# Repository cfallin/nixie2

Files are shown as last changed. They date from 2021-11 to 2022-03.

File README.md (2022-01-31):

# GPS-synchronized Nixie tube clock

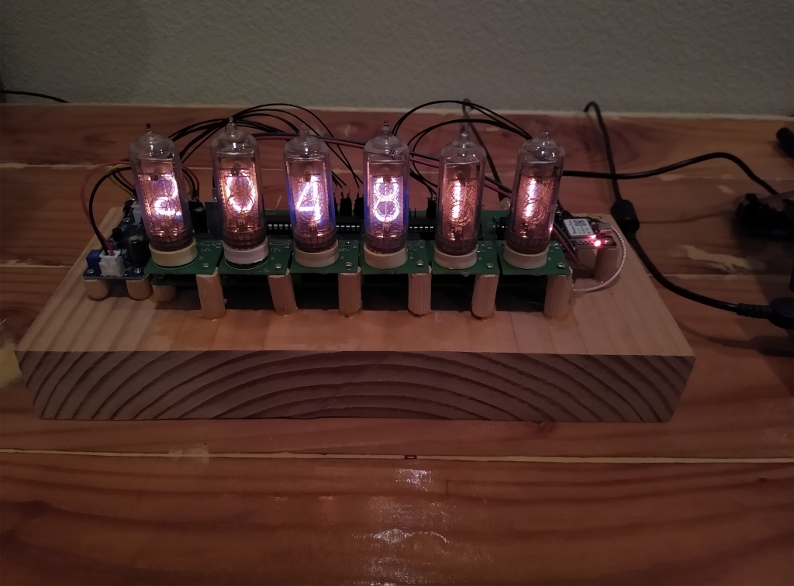
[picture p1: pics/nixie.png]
view of Nixie clock with HH:MM:SS glowing orange digits


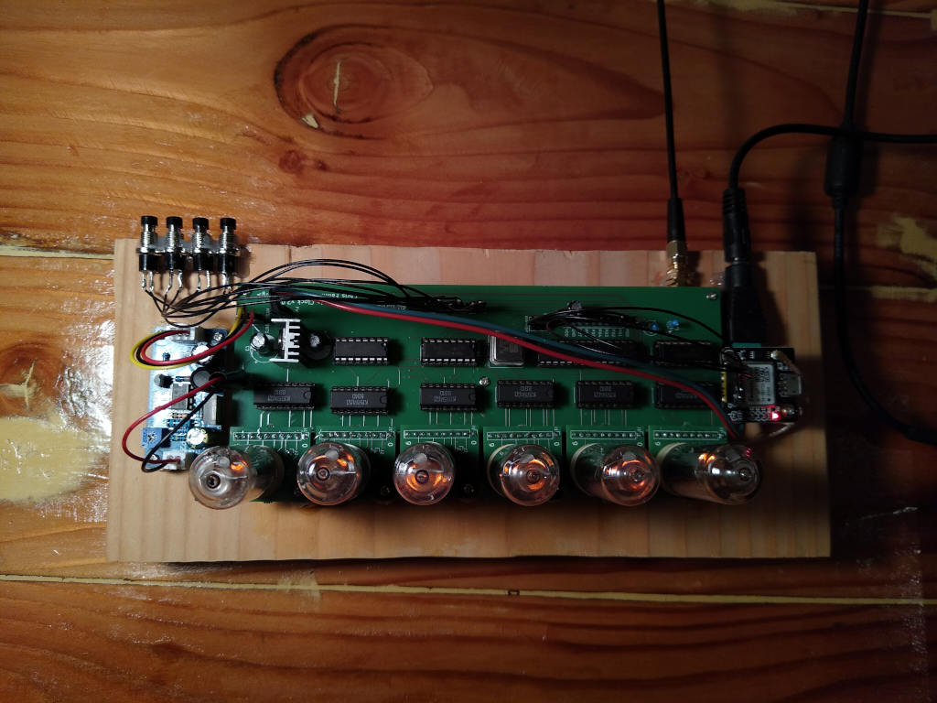
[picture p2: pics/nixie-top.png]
view of Nixie clock from the top, showing circuit boards


This is a custom-designed (custom circuit design / PCB boards and custom
microcontroller firmware) digital clock. It receives the time from a GPS
receiver board, adjusts for an user-selectable timezone, and displays the time
on "Nixie tubes". A [nixie tube](https://en.wikipedia.org/wiki/Nixie_tube) is a
cold-cathode vacuum tube display technology: it uses high voltage (about 160
volts in this design) applied to an electrode in the shape of a digit in order
to display a number in brilliant glowing orange. It really is quite
mesmerizing!

This repo contains custom circuit board layouts for the main clock board and a
separate adapter sub-board for each Nixie tube. The sub-boards are designed for
IN-14 tubes (which can currently be found on eBay or Etsy for ~$20 each), but
could be adapted for IN-12, IN-18, or some other size.

The main board contains an AVR ATmega8 microcontroller, a 20MHz crystal,
several 74HC595 shift registers to expand the AVR's IO, and six KI155ID1
open-collector high voltage driver chips.

The board interfaces with a separate high-voltage DC-DC power supply, because
designing such a supply to be efficient is quite hard and I do not possess the
analog black magic skills! I bought [this
one](https://www.amazon.com/gp/product/B09D94N3MX) for $11. You can substitute
any suitable source of ~160V DC rated for about 4mA per tube (24mA total, or
just under 4 watts).

GPS is also black magic, so I bought a pre-designed GPS receiver module
[here](https://www.amazon.com/gp/product/B07P8YMVNT) for $12, and an external
active antenna [here](https://www.amazon.com/gp/product/B083D59N55) for $11.
The module provides a 1Hz "pulse-per-second" precision output and a 9600bps
serial line providing time, position, and satellite lock information using the
[NMEA](https://en.wikipedia.org/wiki/NMEA_0183) protocol. You can substitute
any GPS receiver that provides a PPS output and NMEA signal.

The ATmega8 runs firmware that decodes the NMEA to get an initial time
(synchronizing whenever a valid NMEA packet with a timestamp is received). It
measures the internal crystal oscillator against the PPS and then ticks based
on the main CPU clock, calibrated with this ticks-per-PPS value. This allows
the clock to receive the time when GPS signal is available, learn how fast or
slow its own internal oscillator is running, and then continue to keep time
when the GPS signal is lost. Whenever it comes back, time will resynchronize
automatically.

There is a simple user interface consisting of four buttons. The leftmost (SW4
on the main board) switches between time mode and set-timezone mode. In the
latter, SW2 decrements TZ offset hour and SW1 increments TZ offset hour.
(Half-hour or 15 minute timezone offsets are not yet supported; I know these
timezones exist, sorry! Happy to take PRs if anyone in such a timezone builds
this clock!)

Total cost for the clock, not including the one-time tool purchases I made
(e.g. an AVR programmer) or the scrap wood, glue, etc. for the very janky base,
and definitely not including my time, was about $230:

- $42 for the PCBs (mainboard and 6x nixie tube adapters) at Aisler.net
- $90 for the six IN-14s, on Etsy
- $22 for the KI155ID1 driver chips
- $12 for the GPS receiver
- $11 for the GPS antenna
- $11 for the 160V DC supply
- about $40 for the ATmega8, 20MHz crystal, 74HC595s, a few resistors and
  capacitors, pin headers, wire, etc.

I started thinking about building a Nixie clock in 2014, but started working on
this design regularly in Nov 2021. It first displayed a GPS-synchronized time
on Jan 6, 2022. I'd like to improve the UI a bit (allow a non-GPS
locally-set-time mode as well), and definitely improve the casing, but it suits
me well enough for now! I finally know what time it is!

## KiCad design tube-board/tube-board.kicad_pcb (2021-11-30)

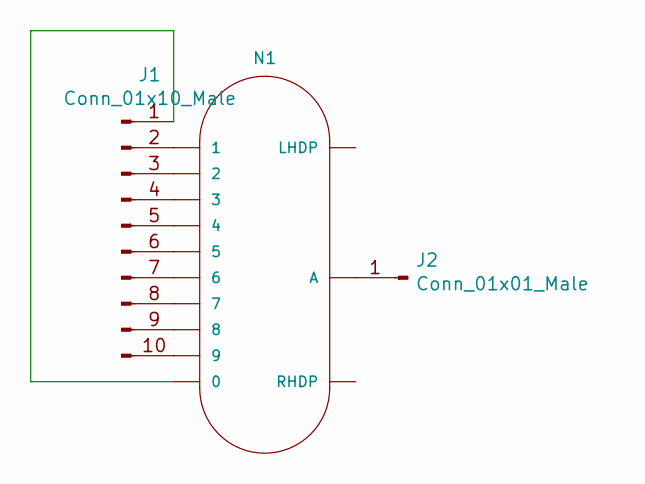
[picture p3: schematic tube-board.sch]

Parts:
J1: Conn_01x10_Male; PinHeader_1x10_P2.54mm_Vertical
J2: Conn_01x01_Male; PinHeader_1x01_P2.54mm_Vertical
N1: IN-14

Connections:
unnamed: J1.1, N1.0
unnamed: J1.2, N1.1
unnamed: J1.3, N1.2
unnamed: J1.4, N1.3
unnamed: J1.5, N1.4
unnamed: J1.6, N1.5
unnamed: J1.7, N1.6
unnamed: J1.8, N1.7
unnamed: J1.9, N1.8
unnamed: J1.10, N1.9
unnamed: J2.1, N1.A

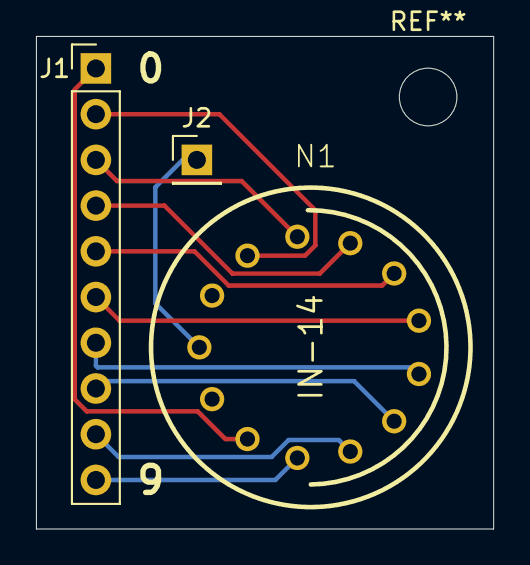
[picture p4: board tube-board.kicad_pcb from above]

Board: 2 copper layers, 25.4 x 27.4 mm, 3 parts (0 on the bottom side), 11 nets.

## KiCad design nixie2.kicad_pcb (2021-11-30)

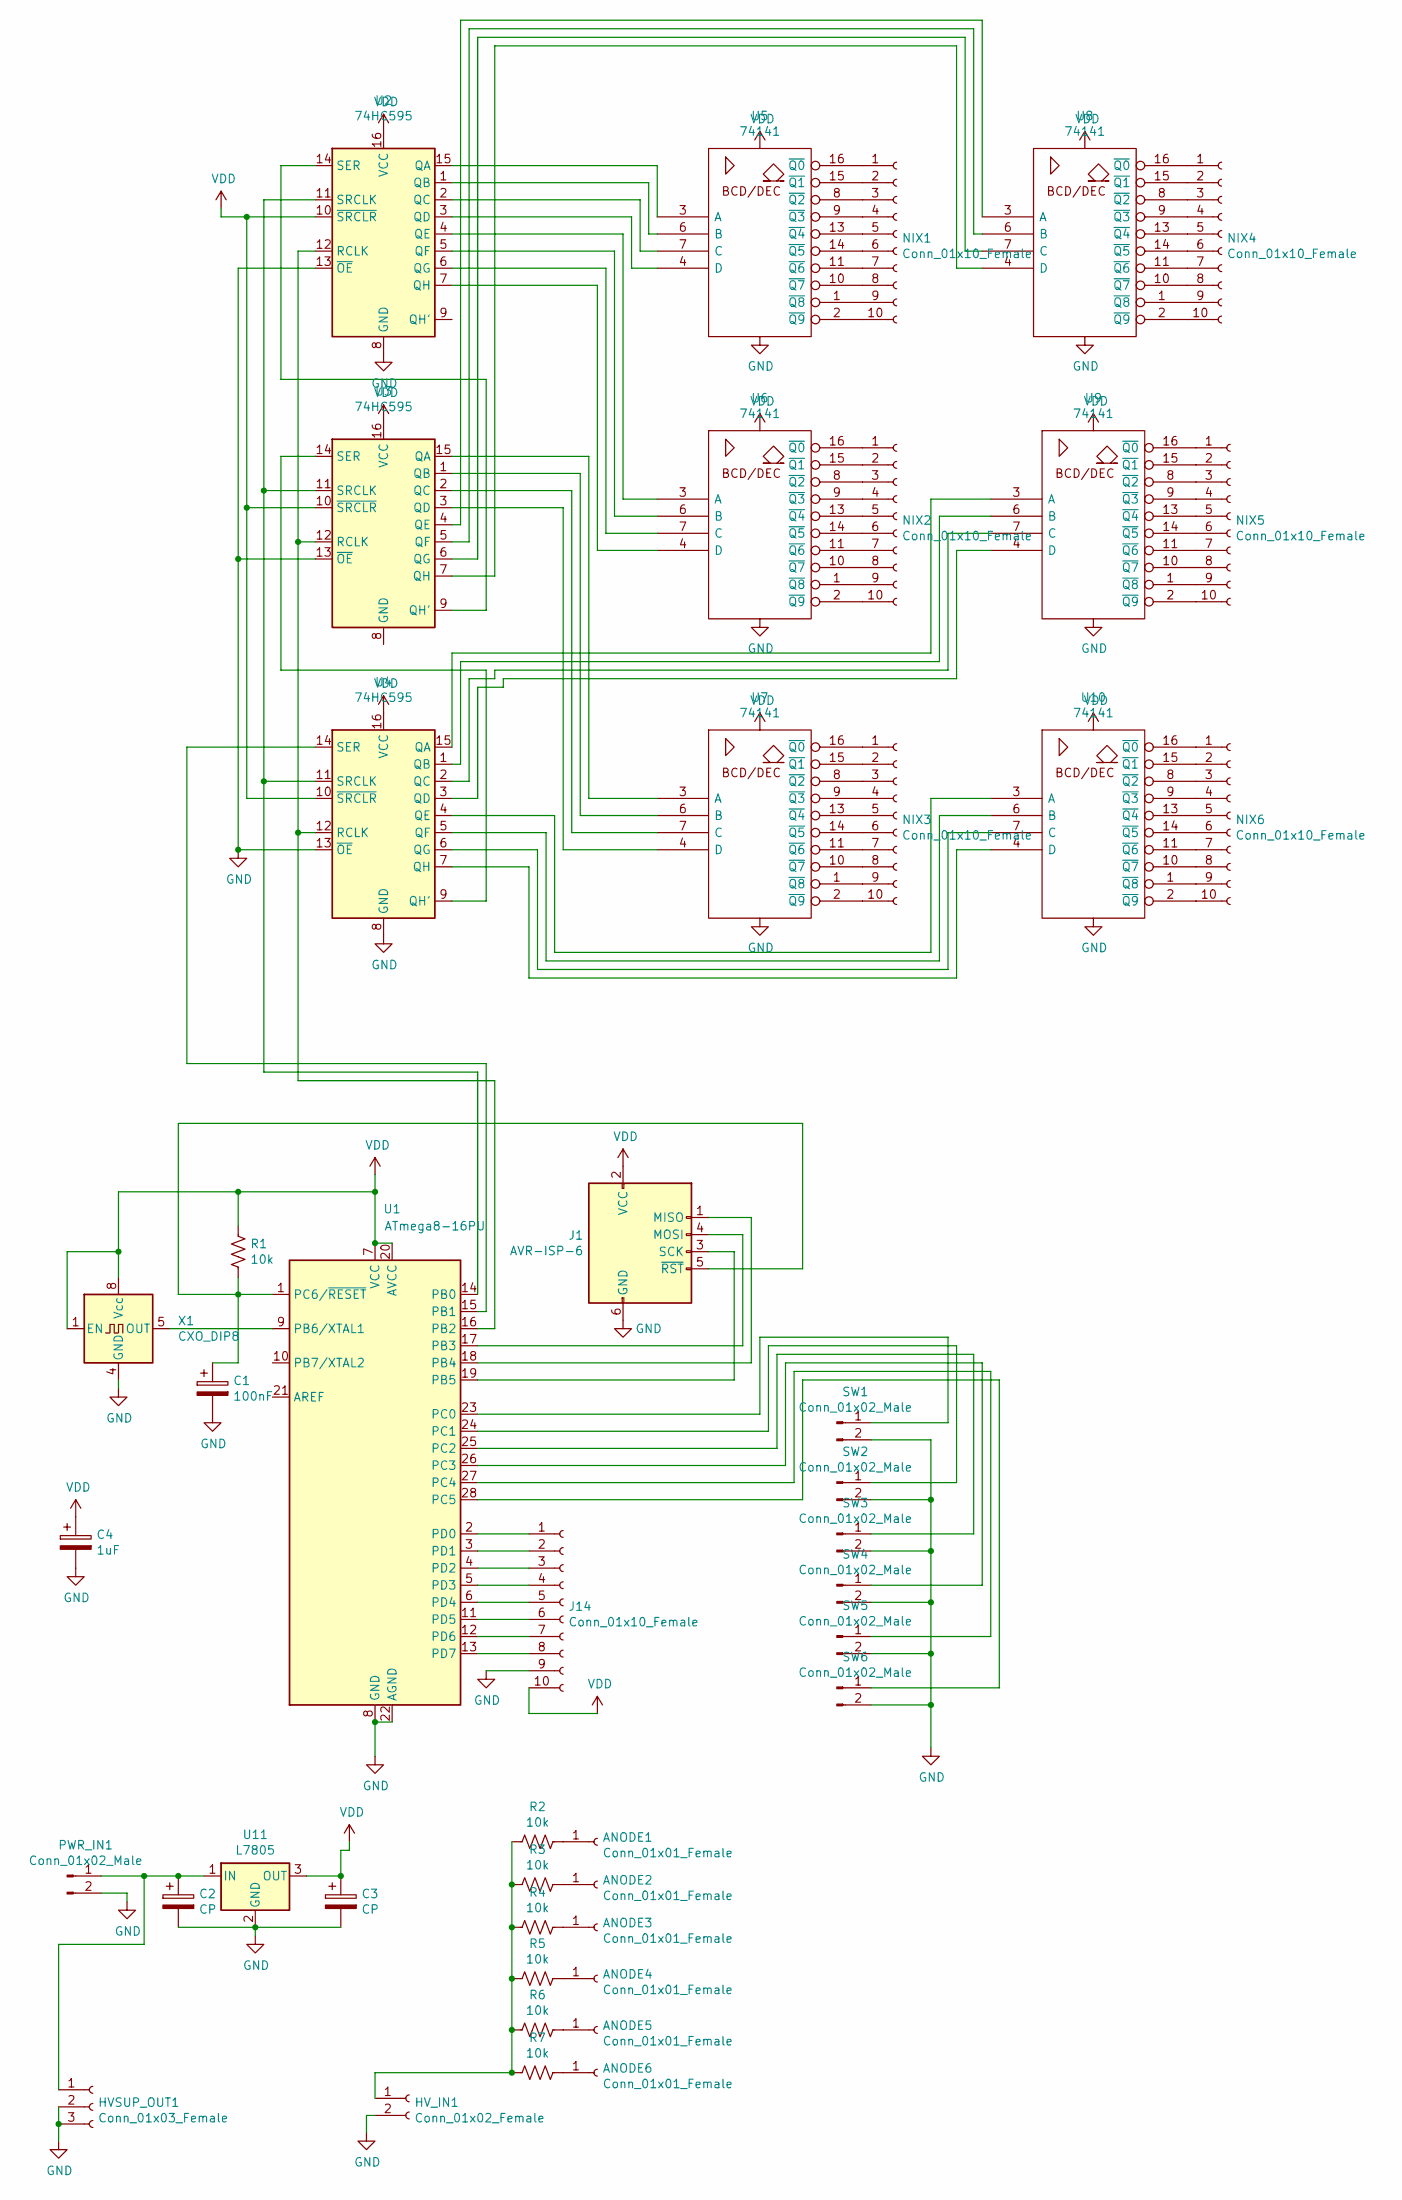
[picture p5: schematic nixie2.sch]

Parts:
ANODE1, ANODE2, ANODE3, ANODE4, ANODE5, ANODE6: Conn_01x01_Female; PinHeader_1x01_P2.54mm_Vertical
C1: 100nF; CP_Radial_Tantal_D5.5mm_P2.50mm
C2, C3: CP; CP_Radial_D10.0mm_P2.50mm
C4: 1uF; CP_Radial_D4.0mm_P1.50mm
HVSUP_OUT1: Conn_01x03_Female; PinHeader_1x03_P2.54mm_Vertical
HV_IN1: Conn_01x02_Female; PinHeader_1x02_P2.54mm_Vertical
J1: AVR-ISP-6; PinHeader_2x03_P2.54mm_Vertical
J14: Conn_01x10_Female; PinHeader_1x10_P2.54mm_Vertical
NIX1, NIX2, NIX3, NIX4, NIX5, NIX6: Conn_01x10_Female; PinHeader_1x10_P2.54mm_Vertical
PWR_IN1: Conn_01x02_Male; PinHeader_1x02_P2.54mm_Vertical
R1: 10k; R_Axial_DIN0207_L6.3mm_D2.5mm_P2.54mm_Vertical
R2, R3, R4, R5, R6, R7: 10k; R_Axial_DIN0207_L6.3mm_D2.5mm_P7.62mm_Horizontal
SW1, SW2, SW3, SW4, SW5, SW6: Conn_01x02_Male; PinHeader_1x02_P2.54mm_Vertical
U1: ATmega8-16PU; DIP-28_W7.62mm
U2, U3, U4: 74HC595; DIP-16_W7.62mm
U5, U6, U7, U8, U9, U10: 74141; DIP-16_W7.62mm
U11: L7805; TO-220-3_Vertical
X1: CXO_DIP8; Oscillator_DIP-8

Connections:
GND: C1.2, C2.2, C3.2, C4.2, HVSUP_OUT1.2, HVSUP_OUT1.3, HV_IN1.2, J1.6 (GND), J14.9, PWR_IN1.2, SW1.2, SW2.2, SW3.2, SW4.2, SW5.2, SW6.2, U1.8 (GND), U1.22 (AGND), U2.8 (GND), U2.13 (~OE), U3.13 (~OE), U4.8 (GND), U4.13 (~OE), U5.12 (GND), U6.12 (GND), U7.12 (GND), U8.12 (GND), U9.12 (GND), U10.12 (GND), U11.2 (GND), X1.4 (GND)
unnamed: ANODE1.1, R2.1
unnamed: ANODE2.1, R3.1
unnamed: ANODE3.1, R4.1
unnamed: ANODE4.1, R5.1
unnamed: ANODE5.1, R6.1
unnamed: ANODE6.1, R7.1
unnamed: C1.1, J1.5 (~RST), R1.2, U1.1 (PC6/~RESET)
unnamed: C2.1, HVSUP_OUT1.1, PWR_IN1.1, U11.1 (IN)
unnamed: HV_IN1.1, R2.2, R3.2, R4.2, R5.2, R6.2, R7.2
unnamed: J1.1 (MISO), U1.18 (PB4)
unnamed: J1.3 (SCK), U1.19 (PB5)
unnamed: J1.4 (MOSI), U1.17 (PB3)
unnamed: J14.1, U1.2 (PD0)
unnamed: J14.2, U1.3 (PD1)
unnamed: J14.3, U1.4 (PD2)
unnamed: J14.4, U1.5 (PD3)
unnamed: J14.5, U1.6 (PD4)
unnamed: J14.6, U1.11 (PD5)
unnamed: J14.7, U1.12 (PD6)
unnamed: J14.8, U1.13 (PD7)
unnamed: NIX1.1, U5.16 (~Q0)
unnamed: NIX1.2, U5.15 (~Q1)
unnamed: NIX1.3, U5.8 (~Q2)
unnamed: NIX1.4, U5.9 (~Q3)
unnamed: NIX1.5, U5.13 (~Q4)
unnamed: NIX1.6, U5.14 (~Q5)
unnamed: NIX1.7, U5.11 (~Q6)
unnamed: NIX1.8, U5.10 (~Q7)
unnamed: NIX1.9, U5.1 (~Q8)
unnamed: NIX1.10, U5.2 (~Q9)
unnamed: NIX2.1, U6.16 (~Q0)
unnamed: NIX2.2, U6.15 (~Q1)
unnamed: NIX2.3, U6.8 (~Q2)
unnamed: NIX2.4, U6.9 (~Q3)
unnamed: NIX2.5, U6.13 (~Q4)
unnamed: NIX2.6, U6.14 (~Q5)
unnamed: NIX2.7, U6.11 (~Q6)
unnamed: NIX2.8, U6.10 (~Q7)
unnamed: NIX2.9, U6.1 (~Q8)
unnamed: NIX2.10, U6.2 (~Q9)
unnamed: NIX3.1, U7.16 (~Q0)
unnamed: NIX3.2, U7.15 (~Q1)
unnamed: NIX3.3, U7.8 (~Q2)
unnamed: NIX3.4, U7.9 (~Q3)
unnamed: NIX3.5, U7.13 (~Q4)
unnamed: NIX3.6, U7.14 (~Q5)
unnamed: NIX3.7, U7.11 (~Q6)
unnamed: NIX3.8, U7.10 (~Q7)
unnamed: NIX3.9, U7.1 (~Q8)
unnamed: NIX3.10, U7.2 (~Q9)
unnamed: NIX4.1, U8.16 (~Q0)
unnamed: NIX4.2, U8.15 (~Q1)
unnamed: NIX4.3, U8.8 (~Q2)
unnamed: NIX4.4, U8.9 (~Q3)
unnamed: NIX4.5, U8.13 (~Q4)
unnamed: NIX4.6, U8.14 (~Q5)
unnamed: NIX4.7, U8.11 (~Q6)
unnamed: NIX4.8, U8.10 (~Q7)
unnamed: NIX4.9, U8.1 (~Q8)
unnamed: NIX4.10, U8.2 (~Q9)
unnamed: NIX5.1, U9.16 (~Q0)
unnamed: NIX5.2, U9.15 (~Q1)
unnamed: NIX5.3, U9.8 (~Q2)
unnamed: NIX5.4, U9.9 (~Q3)
unnamed: NIX5.5, U9.13 (~Q4)
unnamed: NIX5.6, U9.14 (~Q5)
unnamed: NIX5.7, U9.11 (~Q6)
unnamed: NIX5.8, U9.10 (~Q7)
unnamed: NIX5.9, U9.1 (~Q8)
unnamed: NIX5.10, U9.2 (~Q9)
unnamed: NIX6.1, U10.16 (~Q0)
unnamed: NIX6.2, U10.15 (~Q1)
unnamed: NIX6.3, U10.8 (~Q2)
unnamed: NIX6.4, U10.9 (~Q3)
unnamed: NIX6.5, U10.13 (~Q4)
unnamed: NIX6.6, U10.14 (~Q5)
unnamed: NIX6.7, U10.11 (~Q6)
unnamed: NIX6.8, U10.10 (~Q7)
unnamed: NIX6.9, U10.1 (~Q8)
unnamed: NIX6.10, U10.2 (~Q9)
unnamed: SW1.1, U1.23 (PC0)
unnamed: SW2.1, U1.24 (PC1)
unnamed: SW3.1, U1.25 (PC2)
unnamed: SW4.1, U1.26 (PC3)
unnamed: SW5.1, U1.27 (PC4)
unnamed: SW6.1, U1.28 (PC5)
unnamed: U1.9 (PB6/XTAL1), X1.5 (OUT)
unnamed: U1.14 (PB0), U2.11 (SRCLK), U3.11 (SRCLK), U4.11 (SRCLK)
unnamed: U1.15 (PB1), U4.14 (SER)
unnamed: U1.16 (PB2), U2.12 (RCLK), U3.12 (RCLK), U4.12 (RCLK)
unnamed: U2.1 (QB), U5.6 (B)
unnamed: U2.2 (QC), U5.7 (C)
unnamed: U2.3 (QD), U5.4 (D)
unnamed: U2.4 (QE), U6.3 (A)
unnamed: U2.5 (QF), U6.6 (B)
unnamed: U2.6 (QG), U6.7 (C)
unnamed: U2.7 (QH), U6.4 (D)
unnamed: U2.14 (SER), U3.9 (QH')
unnamed: U2.15 (QA), U5.3 (A)
unnamed: U3.1 (QB), U7.6 (B)
unnamed: U3.2 (QC), U7.7 (C)
unnamed: U3.3 (QD), U7.4 (D)
unnamed: U3.4 (QE), U8.3 (A)
unnamed: U3.5 (QF), U8.6 (B)
unnamed: U3.6 (QG), U8.7 (C)
unnamed: U3.7 (QH), U8.4 (D)
unnamed: U3.14 (SER), U4.9 (QH')
unnamed: U3.15 (QA), U7.3 (A)
unnamed: U4.1 (QB), U9.6 (B)
unnamed: U4.2 (QC), U9.7 (C)
unnamed: U4.3 (QD), U9.4 (D)
unnamed: U4.15 (QA), U9.3 (A)
unnamed: U4.4 (QE), U10.3 (A)
unnamed: U4.7 (QH), U10.4 (D)
unnamed: U4.5 (QF), U10.6 (B)
unnamed: U4.6 (QG), U10.7 (C)
VCC: C3.1, C4.1, J1.2 (VCC), J14.10, R1.1, U1.7 (VCC), U1.20 (AVCC), U2.10 (~SRCLR), U2.16 (VCC), U3.10 (~SRCLR), U3.16 (VCC), U4.10 (~SRCLR), U4.16 (VCC), U5.5 (VCC), U6.5 (VCC), U7.5 (VCC), U8.5 (VCC), U9.5 (VCC), U10.5 (VCC), U11.3 (OUT), X1.1 (EN), X1.8 (Vcc)

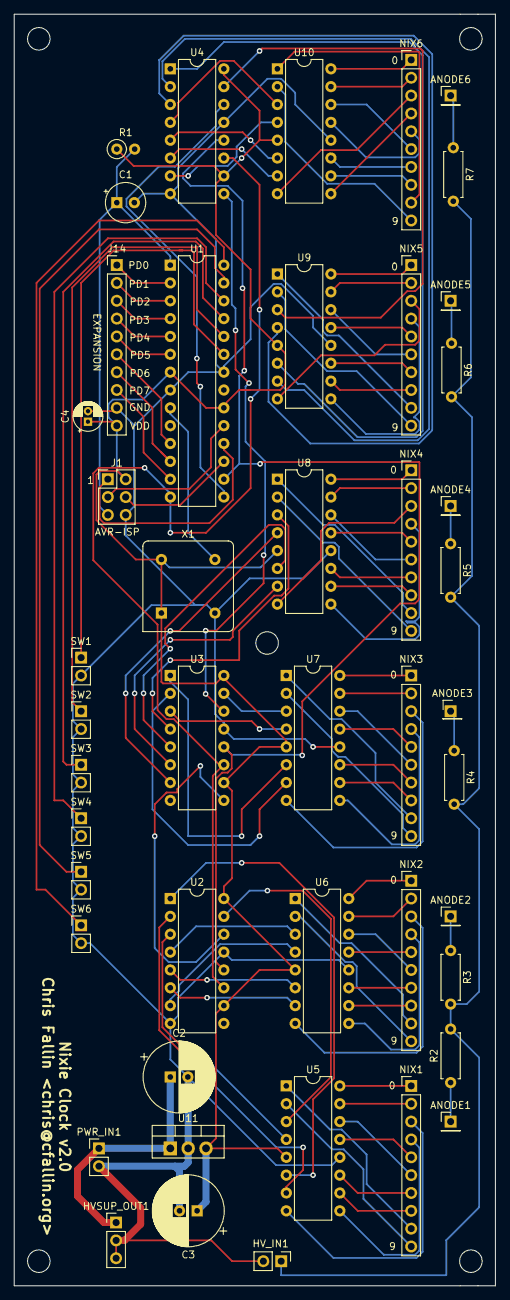
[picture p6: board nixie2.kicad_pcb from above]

Board: 2 copper layers, 68.5 x 181.0 mm, 46 parts (0 on the bottom side), 118 nets.

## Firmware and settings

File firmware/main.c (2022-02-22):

/*
 * Nixie Clock v2.0
 *
 * Copyright (c) 2022 Chris Fallin <chris@cfallin.org>
 * Placed under the Apache-2.0 license.
 */

/* 
 * Assume an ATmega8.
 *
 * IO connections (manufactured board version):
 *
 * PB0 is shift register clock (active high to shift).
 * PB1 is shift register data.
 * PB2 is shift register latch (active high to latch).
 *
 * Shift register output is nixie 2, 1; 4, 3; 6, 5. MSB first of BCD digits.
 *
 * PC0..PC5 are switches 0..5 (to ground; need internal pullups).
 *
 * PD0..PD7 are expansion port.
 */

#include <avr/interrupt.h>

#include "nixie.h"

#define EXPECTED_TIMER_TICKS_PER_SEC 78125 // 20MHz / 256

long timer_ticks = 0;
long hz = EXPECTED_TIMER_TICKS_PER_SEC;
uint8_t time_h = 0, time_m = 0, time_s = 0;

#define DISPLAY_TIME 0
#define DISPLAY_SET 1
#define DISPLAY_CAL 2
int display_mode = 0;

#define UI_TIME 0
#define UI_TO_SET 1
#define UI_SET 2
#define UI_SET_NEXT 3
#define UI_SET_PLUS 4
#define UI_SET_MINUS 5

#define UI_TO_SET_CAL 6
#define UI_SET_CAL 7
#define UI_SET_CAL_NEXT 8
#define UI_SET_CAL_PLUS 9
#define UI_SET_CAL_MINUS 10
#define UI_TO_TIME 11

int ui_state = 0;
int ui_set_digit = 0;

void do_ui() {

    switch (ui_state) {
    case UI_TIME:
        display_mode = DISPLAY_TIME;
        if (switches & 8) {
            ui_state = UI_TO_SET;
        }
        break;
    case UI_TO_SET:
        display_mode = DISPLAY_TIME;
        if (!(switches & 8)) {
            ui_state = UI_SET;
            ui_set_digit = 0;
        }
        break;
    case UI_SET:
        display_mode = DISPLAY_SET;
        if (switches & 8) {
            ui_state = UI_TO_SET_CAL;
        } else if (switches & 4) {
            ui_set_digit++;
            if (ui_set_digit == 3) {
                ui_set_digit = 0;
            }
            ui_state = UI_SET_NEXT;
        } else if (switches & 2) {
            switch (ui_set_digit) {
                case 0:
                    time_h++;
                    if (time_h == 24) {
                        time_h = 0;
                    }
                    break;
                case 1:
                    time_m++;
                    if (time_m == 60) {
                        time_m = 0;
                    }
                    break;
                case 2:
                    time_s++;
                    if (time_s == 60) {
                        time_s = 0;
                    }
                    break;
            }
            ui_state = UI_SET_PLUS;
        } else if (switches & 1) {
            switch (ui_set_digit) {
                case 0:
                    if (time_h == 0) {
                        time_h = 24;
                    }
                    time_h--;
                    break;
                case 1:
                    if (time_m == 0) {
                        time_m = 60;
                    }
                    time_m--;
                    break;
                case 2:
                    if (time_s == 0) {
                        time_s = 60;
                    }
                    time_s--;
                    break;
            }
            ui_state = UI_SET_MINUS;
        }
        break;
    case UI_SET_NEXT:
        display_mode = DISPLAY_SET;
        if (!(switches & 4)) {
            ui_state = UI_SET;
        }
        break;
    case UI_SET_PLUS:
        display_mode = DISPLAY_SET;
        if (switches & 1) {
            switch (ui_set_digit) {
                case 0:
                    time_h = 0;
                    break;
                case 1:
                    time_m = 0;
                    break;
                case 2:
                    time_s = 0;
                    break;
            }
        } else if (!(switches & 2)) {
            ui_state = UI_SET;
        }
        break;
    case UI_SET_MINUS:
        display_mode = DISPLAY_SET;
        if (switches & 2) {
            switch (ui_set_digit) {
                case 0:
                    time_h = 0;
                    break;
                case 1:
                    time_m = 0;
                    break;
                case 2:
                    time_s = 0;
                    break;
            }
        } else if (!(switches & 1)) {
            ui_state = UI_SET;
        }
        break;
    case UI_TO_SET_CAL:
        display_mode = DISPLAY_SET;
        if (!(switches & 8)) {
            ui_state = UI_SET_CAL;
            ui_set_digit = 0;
        }
        break;
    case UI_SET_CAL:
        display_mode = DISPLAY_CAL;
        if (switches & 8) {
            ui_state = UI_TO_TIME;
        } else if (switches & 4) {
            ui_set_digit++;
            if (ui_set_digit == 5) {
                ui_set_digit = 0;
            }
            ui_state = UI_SET_CAL_NEXT;
        } else if (switches & 2) {
            int amt = 1;
            for (int i = 0; i < (4 - ui_set_digit); i++) {
                amt *= 10;
            }
            hz += amt;
            if (hz > 100000) {
                hz -= 100000;
            }
            ui_state = UI_SET_CAL_PLUS;
        } else if (switches & 1) {
            int amt = 1;
            for (int i = 0; i < (4 - ui_set_digit); i++) {
                amt *= 10;
            }
            hz -= amt;
            if (hz < amt) {
                hz += 100000;
            }
            ui_state = UI_SET_CAL_MINUS;
        }
        break;
    case UI_SET_CAL_NEXT:
        display_mode = DISPLAY_CAL;
        if (!(switches & 4)) {
            ui_state = UI_SET_CAL;
        }
        break;
    case UI_SET_CAL_PLUS:
        display_mode = DISPLAY_CAL;
        if (!(switches & 2)) {
            ui_state = UI_SET_CAL;
        }
        break;
    case UI_SET_CAL_MINUS:
        display_mode = DISPLAY_CAL;
        if (!(switches & 1)) {
            ui_state = UI_SET_CAL;
        }
        break;
    case UI_TO_TIME:
        display_mode = DISPLAY_CAL;
        if (!(switches & 8)) {
            ui_state = UI_TIME;
        }
        break;
    }
}

void update_display() {
    switch (display_mode) {
    case DISPLAY_TIME: {
        display_digits(time_h / 10, time_h % 10, time_m / 10, time_m % 10, time_s / 10, time_s % 10);
        break;
    }
    case DISPLAY_SET: {
        int second_half_second = timer_ticks > (hz / 2);
        int h1 = 15, h2 = 15, m1 = 15, m2 = 15, s1 = 15, s2 = 15;

        if (ui_set_digit != 0 || !second_half_second) {
            h1 = time_h / 10;
            h2 = time_h % 10;
        }
        if (ui_set_digit != 1 || !second_half_second) {
            m1 = time_m / 10;
            m2 = time_m % 10;
        }
        if (ui_set_digit != 2 || !second_half_second) {
            s1 = time_s / 10;
            s2 = time_s % 10;
        }
        display_digits(h1, h2, m1, m2, s1, s2);
        break;
    }
    case DISPLAY_CAL: {
        int second_half_second = timer_ticks > (hz / 2);
        int d1 = 15, d2 = 15, d3 = 15, d4 = 15, d5 = 15;

        if (ui_set_digit != 0 || !second_half_second) {
            d1 = (hz / 10000) % 10;
        }
        if (ui_set_digit != 1 || !second_half_second) {
            d2 = (hz / 1000) % 10;
        }
        if (ui_set_digit != 2 || !second_half_second) {
            d3 = (hz / 100) % 10;
        }
        if (ui_set_digit != 3 || !second_half_second) {
            d4 = (hz / 10) % 10;
        }
        if (ui_set_digit != 4 || !second_half_second) {
            d5 = hz % 10;
        }
        display_digits(15, d1, d2, d3, d4, d5);
    }
    }
}

int main()
{
    init_display();
    init_usart();
    init_switches();
    enable_timer_interrupt();
    sei();


    int pos = 0;
    int state = 0;
    while (1) {
        delay();
        read_switches();
        do_ui();
        update_display();
    }
}

void do_second() {
    time_s++;
    if (time_s == 60) {
        time_s = 0;
        time_m++;
    }
    if (time_m == 60) {
        time_m = 0;
        time_h++;
    }
    if (time_h == 24) {
        time_h = 0;
    }
}

void do_timer_int() {
    timer_ticks++;
    if (timer_ticks >= hz) {
        timer_ticks = 0;
        do_second();
    }
}

void do_serial_time(int h, int m, int s) {
    time_h = h;
    time_m = m;
    time_s = s;
    timer_ticks = 0;
}

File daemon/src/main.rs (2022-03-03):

use chrono::{DateTime, Local};
use std::time::{Duration, SystemTime};

fn main() {
    let port_name = std::env::var("CLOCK_SERIAL_PORT").unwrap_or("/dev/ttyUSB0".into());
    let mut port = serialport::new(&port_name, 115_200)
        .flow_control(serialport::FlowControl::None)
        .open()
        .expect("Could not open port");

    loop {
        let local: DateTime<Local> = DateTime::from(SystemTime::now());
        let local = local.time().format("%H%M%S").to_string();
        writeln!(port, "{}", local).unwrap();
        std::thread::sleep(Duration::from_millis(50));
    }
}

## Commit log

2021-11-29 Initial commit: nixie2 board.
    [nixie2.kicad_pcb, nixie2.sch]
2021-11-30 Add tube adapter board, and tweak main board
    [nixie2.kicad_pcb, nixie2.sch, tube-board.kicad_pcb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]
2021-11-30 Add some mounting holes
    [nixie2.kicad_pcb, tube-board.kicad_pcb]
2021-11-30 Remove extraneous label on mounting hole.
    [nixie2.kicad_pcb]
2021-11-30 Move HV_IN connector to not interfere with NIX1 sub-board.
    [nixie2.kicad_pcb]
2021-11-30 Minor changes to power traces; also remove parallel run between clock line and ISP line.
    [nixie2.kicad_pcb]
2021-11-30 tweak tube board height to not cut off silkscreen
    [tube-board.kicad_pcb]
2022-01-06 Switch debouncing, UART setup, and PPS interrupt
2022-01-31 remove GPS-disciplined-local-oscillator logic for now; need to refine interactions with GPS time sync
    [main.c]
2022-02-20 clock firmware: remove GPS interface for now (unreliable reception); button UI for setting local time
2022-02-25 Restart nixie-clock daemon; otherwise it will die on spurious USB errors and clock will silently drift off true time
2022-03-03 fix time divergence once and for all: daemon updates clock time over serial continuously
    [main.rs]
